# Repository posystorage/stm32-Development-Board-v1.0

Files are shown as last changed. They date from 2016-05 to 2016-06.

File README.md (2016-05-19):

# stm32-Development-Board-v1.0
话说事情起因是一元钱的pos机造成的，记得当初撸的第一个pos机是米刷的，然后就拆了gd32的单片机下来玩，焊在转接板上使用，100脚的转接板，插线很是的困难，经常插错线，还拿着程序调半天没结果。
后来又撸了几个即付宝，里面是stm32的单片机，不想忍受原装板子上基本上所有引脚都没引出，用不了，功能强大的stm32就是个残废，还不如个51，拆下来上转接板又难插线，心塞。
之前想加个小组织，说只会点51被人家鄙视说一点8位单片机搞不了什么大东西，所以想学stm32，看看芯片价格，tm一片（stm32）价格更比3片（51）强，在看看最小系统，tm价格又翻了三倍，开发板更贵了，穷学生伤不起。
正好这个寒假又自学了ad，画了一两个板子，自我感觉还好（其实现在看看一塌糊涂）。
于是在有天出去散步时就萌生了自己做块stm32开发板的想法，计算下感觉蛮合适的，单片机一块钱，板子打样5-6块，其他零件不超20，和起来还比一块最小系统便宜，越想越激动，散步都忙不急看风景了，回来就赶紧研究。
 
最终选择了以正点原子的板子为基础进行改造，这样有个好处，人家电路经过研究肯定没问题，比自己到处找简单，如果引脚差不多一样，程序也可以直接拿过来用，基本不用改，原子的例程，论坛的用这板子的大神的东西，都可以借鉴，同时也加了些玩51的时带不起来的遗憾的东西进去，比如iis、sdio式的sd卡接口、板载stlink（自己没有stlink，买还要钱，不如板载个吧，这样用起了更方便)、也加了平时很难焊接的esp8266焊盘。
这样一加这么多功能发觉，我去，io不够了，想来想去，特别烦躁的过过了两天，想了杜邦线连接式开发板（如有些51开发板就这样），想了各种引脚复用，最后一想到时候实际玩的时候要是刚好接在复用引脚上的东西就不能一起hi了，比如spi和iis只能选一个，用屏幕时不能用sdio等等，那是不是挺麻烦的。
最后做出一个重大的艰难的决定，吧屏幕接口扔了，这样不就省了20多个io，想怎么hi怎么hi，hi完还有剩余io，爽。其实还有另一层打算，之前只玩过12864和1602，对彩屏根本不了解，接口也不熟悉，看了好多款屏幕，各种接口都有，很不统一，如果直接照抄原子哥的屏幕接口，到时候搞不好买不到一样的，还只能去它店里剁手一块他定制的屏幕，那不就比两个自制开发板还贵了么？穷学生玩不起，算了，到时候大不了搞点黑白屏或者全部杜邦线连上，low就low点，自用管他的。

于是就这样，一块板子就做完了（真尼玛说的容易，学ad和stm32入门花了一个月，设计板子用了2周，工厂花了一周，焊接调试查错差不多花了一周，而且这些时间基本上除了正事外整天投入的，连干正事的时候都还经常想着下一步的计划），所以说不容易啊.

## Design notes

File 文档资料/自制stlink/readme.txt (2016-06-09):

1、建议焊接完成刷入固件后更新到最新版本固件
2、在开发板上刷入固件时，不要耍小聪明，一定要注意供电，建议不要用板载的3.3v稳压芯片供电，用下载器供电，必须必须必须接全3.3v、rx、tx（swd、sck）和gnd，不然会像我一样浪费一下午给stlink烧固件。供电问题表现为：串口下载检测不到芯片，stlink能检测到且下载，但校验不通过，检查发现，大半程序没烧入，呵呵，总体建议串口下载
3、板载stlink和主芯片有两个短接焊盘相连，如果只想下主控就连起来，不想就别连，我倒是没连，用杜邦线连，我要下载的板子多，只有这个stlink。

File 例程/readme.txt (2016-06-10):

部分内容与原子的不兼容，自行验证验证过的没问题

暂未测试/未成功内容：

iic，无24l01
iis，代码不会写，暂不测
sdio，原因不明，反正不成功，焊盘也有点问题
can，无芯片
ch340自动下载，买零件那天优信缺货，暂无
ps2，座子插不进去，也没相关设备

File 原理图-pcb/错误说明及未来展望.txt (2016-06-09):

2016/03/08版v1.0

------

问题；严重级别

1、usb差分走线问题；未知，主机和stlink测试无问题
2、pa2和pa3位置错误且丝印错误；中
3、串口rx tx与常用转串口下载器相反，需要交叉接线，麻烦；低
4、usb焊盘太短，芯片焊盘应加长；低
5、FLASH焊盘太短；低
6、板载stlink晶振周围太窄；低
7、ps2接口插不进去；低
8、tf卡（sdio接口）焊盘错误；中高

-----
第二版期望加入的功能：

1、蓝牙模块焊盘
2、usb静电保护芯片

第二版计划删除：
can
ps2
iis接口的adc芯片cs4344
esp8266
板载stlink

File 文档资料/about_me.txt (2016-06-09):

这是一块功能强大的stm32单片机开发板，由一个第一次画pcb的小屁孩逗逼制作。
起因是一元钱的pos机造成的，记得当初撸的第一个pos机是米刷的，然后就拆了gd32的单片机下来玩，焊在转接板上使用，100脚的转接板，插线很是的困难，经常插错线，还拿着程序调半天没结果。后来又撸了几个即付宝，里面是stm32的单片机，不想忍受原装板子上引脚基本用不了，功能强大的stm32就是个残废，拆下来上转接板又难插线，心塞。之前想加个小组织，说只会点51被人家鄙视说一点8位单片机搞不了什么大东西，所以想学stm32，看看芯片价格，tm一片（stm32）价格更比3片（51）强，在看看最小系统，tm价格又翻了三倍，开发板更贵了，穷学生伤不起。正好这个寒假又自学了ad，画了一两个板子，自我感觉还好（其实现在看看一塌糊涂）。于是在有天出去散步时就萌生了自己做块stm32开发板的想法，计算下感觉蛮合适的，单片机一块钱，板子打样5-6块，其他零件不超20，和起来还比一块最小系统便宜，越想越激动，散步都忙不急看风景了，回来就赶紧研究，最终选择了以正点原子的板子为基础进行改造，这样有个好处，人家电路经过研究肯定没问题，比自己到处找简单，如果引脚差不多一样，程序也可以直接拿过来用，基本不用改，原子的例程，论坛的用这板子的大神的东西，都可以借鉴，同时也加了些玩51的时带不起来的遗憾的东西进去，比如iis、sdio式的sd卡接口、板载stlink（自己没有stlink，买还要钱，不如板载个吧，这样用起了更方便)、也加了平时很难焊接的esp8266焊盘。这样一加发觉我去，io不够了，想来想去，特别烦躁的过过了两天，想了杜邦线连接式开发板（如有些51开发板就这样），想了各种引脚复用，最后一想到时候实际玩的时候要是刚好接在复用引脚上的东西就不能一起hi了，比如spi和iis只能选一个，用屏幕时不能用sdio等等，那是不是挺麻烦的。最后做出一个重大的艰难的决定，吧屏幕接口扔了，这样不就省了20多个io，想怎么hi怎么hi，hi、玩还有剩余io，爽。其实还有另一层打算，之前只玩过12864和1602，对彩屏根本不了解，接口也不熟悉，看了好多款屏幕，各种接口都有，很不统一，如果直接照抄原子哥的屏幕接口，到时候搞不好买不到一样的，还只能去它店里剁手一块他定制的屏幕，那不就比两个自制开发板还贵了么？穷学生玩不起，算了，到时候大不了搞点黑白屏或者全部杜邦线连上，low就low点，自用管他的。于是就这样，一块板子就做完了（真尼玛说的容易，学ad和stm32入门花了一个月，设计板子用了2周，工厂花了一周，焊接调试查错差不多花了一周，而且这些时间基本上除了正事外整天投入的，连干正事的时候都还经常想着下一步的计划），所以说不容易啊，就此先感谢大家的支持，你们的支持是我第二版的动力

关于第二版：
短期内暂时不想做，最近事多，干这个至少要报废一个月
如果坛友们的呼声特别大，才考虑
毕竟第一版问题不算太多，可以接受，不是急需第二版
还有其他项目

https://stm32-posystorage.rhcloud.com

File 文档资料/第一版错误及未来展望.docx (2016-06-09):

2016/03/08版v1.0

问题；严重级别

1、 usb差分走线问题；未知，主机和stlink测试无问题

板载stlink小概率不正常，不能识别上usb，主usb暂无此问题

2、pa2和pa3位置错误且丝印错误；中

Pa2的位置实际是pa3

Pa3的位置实际是pa2

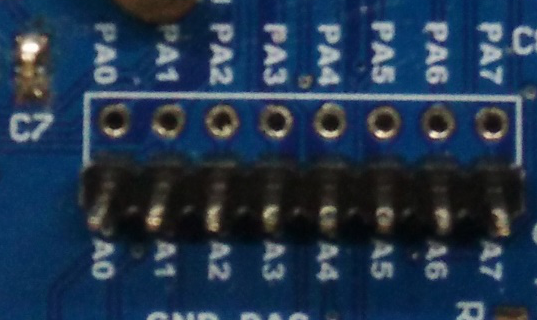
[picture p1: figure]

3、串口rx tx与常用转串口下载器相反，需要交叉接线，麻烦；低

4、usb焊盘太短，芯片焊盘应加长；低

5、FLASH焊盘太短；低

6、板载stlink晶振周围太窄；低

7、ps2接口插不进去；低

8、tf卡（sdio接口）焊盘错误；中高

只能这样焊才对，有点蛋疼

且程序验证暂未通过

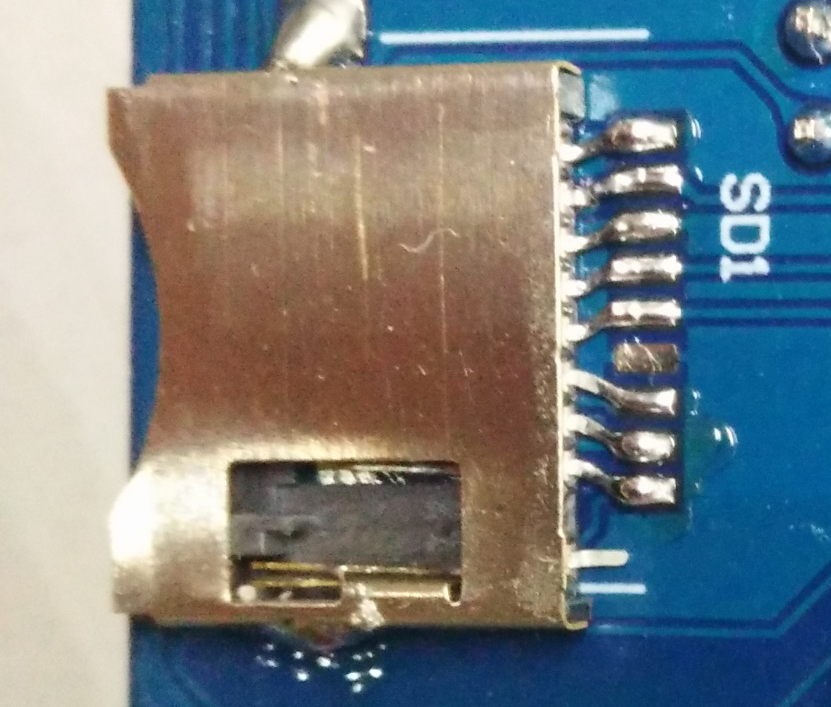
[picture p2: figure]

第二版期望加入的功能：

1、蓝牙模块焊盘

2、usb静电保护芯片

第二版计划删除：

can

ps2

iis接口的adc芯片cs4344

esp8266

板载stlink

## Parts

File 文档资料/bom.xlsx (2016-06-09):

简易bom表，凭记忆，可能不完全，注意复查，以电路图为准
名称 | 封装 | 数量 | 备注
stm32f103rct6 |  | 1
stm32f103c8t6 |  | 1
8m晶振 |  | 2
12m晶振 |  | 1
时钟晶振 | 圆柱 | 1
排针排座 |  | 若干
自恢复保险丝 | 1812 | 1 | 500ma
usb | micro | 3
1n4148 | 1206 | 1
耳机座 |  | 1
ps/2插座 |  | 1
按键 |  | 4
led | 0805以下 | 5
ams1117-3.3 |  | 1
led5050 | 5050 | 1 | 三色
8550 | SOT-23B_N | 1
8050 | SOT-24B_N | 1
电阻 | 0805以下 | 若干 | 1m,47k,10k,4k7,1k5,1k,r100,r22
电容 | 0805以下 | 若干 | 106,104(多),22p
电解电容 |  | 6 | 3.3uf，其他
tf卡座 |  | 1 | 优信有卖同封装
sd卡座 |  | 1 | 优信有卖同封装
tja1050 | sop8 | 1
短路帽 |  | 4
ch340 |  | 1
cs4344 |  | 1
25q32 |  | 1 | flash
esp8266模块 | esp12f | 1

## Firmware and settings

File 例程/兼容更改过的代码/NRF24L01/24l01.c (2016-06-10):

#include "24l01.h"
#include "delay.h"
#include "spi.h"
//////////////////////////////////////////////////////////////////////////////////	 
//本程序只供学习使用，未经作者许可，不得用于其它任何用途
//ALIENTEK MiniSTM32开发板
//NRF24L01驱动代码	   
//正点原子@ALIENTEK
//技术论坛:www.openedv.com
//修改日期:2014/3/12
//版本：V1.0
//版权所有，盗版必究。
//Copyright(C) 广州市星翼电子科技有限公司 2009-2019
//All rights reserved									  
//////////////////////////////////////////////////////////////////////////////////
    
const u8 TX_ADDRESS[TX_ADR_WIDTH]={0x34,0x43,0x10,0x10,0x01}; //发送地址
const u8 RX_ADDRESS[RX_ADR_WIDTH]={0x34,0x43,0x10,0x10,0x01}; //发送地址


//初始化24L01的IO口

void NRF24L01_Init(void)
{  
	GPIO_InitTypeDef GPIO_InitStructure;
	SPI_InitTypeDef  SPI_InitStructure; 
	
 	RCC_APB2PeriphClockCmd(	RCC_APB2Periph_GPIOA|RCC_APB2Periph_GPIOB|RCC_APB2Periph_GPIOC, ENABLE );	
	
	GPIO_InitStructure.GPIO_Pin = GPIO_Pin_2|GPIO_Pin_3|GPIO_Pin_4;
	GPIO_InitStructure.GPIO_Mode = GPIO_Mode_Out_PP ;   //推挽输出
	GPIO_InitStructure.GPIO_Speed = GPIO_Speed_50MHz;
	GPIO_Init(GPIOA, &GPIO_InitStructure);
	
	GPIO_InitStructure.GPIO_Pin = GPIO_Pin_4;
	GPIO_InitStructure.GPIO_Mode = GPIO_Mode_Out_PP ;   //推挽输出
	GPIO_InitStructure.GPIO_Speed = GPIO_Speed_50MHz;
	GPIO_Init(GPIOC, &GPIO_InitStructure); 
	GPIO_SetBits(GPIOC,GPIO_Pin_4);
		
	GPIO_InitStructure.GPIO_Pin = GPIO_Pin_0;
	GPIO_InitStructure.GPIO_Mode = GPIO_Mode_Out_PP ;   //推挽输出
	GPIO_InitStructure.GPIO_Speed = GPIO_Speed_50MHz;
	GPIO_Init(GPIOB, &GPIO_InitStructure); 
	GPIO_SetBits(GPIOB,GPIO_Pin_0);
	
	GPIO_InitStructure.GPIO_Pin = GPIO_Pin_1;
	GPIO_InitStructure.GPIO_Mode = GPIO_Mode_IPU  ;   //上拉输入
	GPIO_InitStructure.GPIO_Speed = GPIO_Speed_50MHz;
	GPIO_Init(GPIOA, &GPIO_InitStructure);

	GPIO_SetBits(GPIOA,GPIO_Pin_1|GPIO_Pin_2|GPIO_Pin_3|GPIO_Pin_4);
	SPI1_Init();    		//初始化SPI
		
	SPI_Cmd(SPI1, DISABLE); // 
	
	SPI_InitStructure.SPI_Direction = SPI_Direction_2Lines_FullDuplex;  //设置SPI单向或者双向的数据模式:SPI设置为双线双向全双工
	SPI_InitStructure.SPI_Mode = SPI_Mode_Master;		//设置SPI工作模式:设置为主SPI
	SPI_InitStructure.SPI_DataSize = SPI_DataSize_8b;		//设置SPI的数据大小:SPI发送接收8位帧结构
	SPI_InitStructure.SPI_CPOL = SPI_CPOL_Low;		//选择了串行时钟的稳态:时钟悬空低电平
	SPI_InitStructure.SPI_CPHA = SPI_CPHA_1Edge;	//数据捕获于第一个时钟沿
	SPI_InitStructure.SPI_NSS = SPI_NSS_Soft;		//NSS信号由硬件（NSS管脚）还是软件（使用SSI位）管理:内部NSS信号有SSI位控制
	SPI_InitStructure.SPI_BaudRatePrescaler = SPI_BaudRatePrescaler_256;		//定义波特率预分频的值:波特率预分频值为256
	SPI_InitStructure.SPI_FirstBit = SPI_FirstBit_MSB;	//指定数据传输从MSB位还是LSB位开始:数据传输从MSB位开始
	SPI_InitStructure.SPI_CRCPolynomial = 7;	//CRC值计算的多项式
	SPI_Init(SPI1, &SPI_InitStructure);  //根据SPI_InitStruct中指定的参数初始化外设SPIx寄存器

	
	NRF24L01_CE=0; 	//使能24L01
	NRF24L01_CSN=1;	//SPI片选取消	 	
}
//检测24L01是否存在
//返回值:0，成功;1，失败	
u8 NRF24L01_Check(void)
{
	u8 buf[5]={0XA5,0XA5,0XA5,0XA5,0XA5};
	u8 i;
	SPI1_SetSpeed(SPI_BaudRatePrescaler_8); //spi速度为9Mhz（24L01的最大SPI时钟为10Mhz）   	 
	NRF24L01_Write_Buf(NRF_WRITE_REG+TX_ADDR,buf,5);//写入5个字节的地址.	
	NRF24L01_Read_Buf(TX_ADDR,buf,5); //读出写入的地址  
	for(i=0;i<5;i++)if(buf[i]!=0XA5)break;	 							   
	if(i!=5)return 1;//检测24L01错误	
	return 0;		 //检测到24L01
}	 	 
//SPI写寄存器
//reg:指定寄存器地址
//value:写入的值
u8 NRF24L01_Write_Reg(u8 reg,u8 value)
{
	u8 status;	
   	NRF24L01_CSN=0;                 //使能SPI传输
  	status =SPI1_ReadWriteByte(reg);//发送寄存器号 
  	SPI1_ReadWriteByte(value);      //写入寄存器的值
  	NRF24L01_CSN=1;                 //禁止SPI传输	   
  	return(status);       			//返回状态值
}
//读取SPI寄存器值
//reg:要读的寄存器
u8 NRF24L01_Read_Reg(u8 reg)
{
	u8 reg_val;	    
 	NRF24L01_CSN = 0;          //使能SPI传输		
  	SPI1_ReadWriteByte(reg);   //发送寄存器号
  	reg_val=SPI1_ReadWriteByte(0XFF);//读取寄存器内容
  	NRF24L01_CSN = 1;          //禁止SPI传输		    
  	return(reg_val);           //返回状态值
}	
//在指定位置读出指定长度的数据
//reg:寄存器(位置)
//*pBuf:数据指针
//len:数据长度
//返回值,此次读到的状态寄存器值 
u8 NRF24L01_Read_Buf(u8 reg,u8 *pBuf,u8 len)
{
	u8 status,u8_ctr;	       
  	NRF24L01_CSN = 0;           //使能SPI传输
  	status=SPI1_ReadWriteByte(reg);//发送寄存器值(位置),并读取状态值   	   
 	for(u8_ctr=0;u8_ctr<len;u8_ctr++)pBuf[u8_ctr]=SPI1_ReadWriteByte(0XFF);//读出数据
  	NRF24L01_CSN=1;       //关闭SPI传输
  	return status;        //返回读到的状态值
}
//在指定位置写指定长度的数据
//reg:寄存器(位置)
//*pBuf:数据指针
//len:数据长度
//返回值,此次读到的状态寄存器值
u8 NRF24L01_Write_Buf(u8 reg, u8 *pBuf, u8 len)
{
	u8 status,u8_ctr;	    
 	NRF24L01_CSN = 0;          //使能SPI传输
  	status = SPI1_ReadWriteByte(reg);//发送寄存器值(位置),并读取状态值
  	for(u8_ctr=0; u8_ctr<len; u8_ctr++)SPI1_ReadWriteByte(*pBuf++); //写入数据	 
  	NRF24L01_CSN = 1;       //关闭SPI传输
  	return status;          //返回读到的状态值
}				   
//启动NRF24L01发送一次数据
//txbuf:待发送数据首地址
//返回值:发送完成状况
u8 NRF24L01_TxPacket(u8 *txbuf)
{
	u8 sta;
 	SPI1_SetSpeed(SPI_BaudRatePrescaler_8);//spi速度为9Mhz（24L01的最大SPI时钟为10Mhz）   
	NRF24L01_CE=0;
  	NRF24L01_Write_Buf(WR_TX_PLOAD,txbuf,TX_PLOAD_WIDTH);//写数据到TX BUF  32个字节
 	NRF24L01_CE=1;//启动发送	   
	while(NRF24L01_IRQ!=0);//等待发送完成
	sta=NRF24L01_Read_Reg(STATUS);  //读取状态寄存器的值	   
	NRF24L01_Write_Reg(NRF_WRITE_REG+STATUS,sta); //清除TX_DS或MAX_RT中断标志
	if(sta&MAX_TX)//达到最大重发次数
	{
		NRF24L01_Write_Reg(FLUSH_TX,0xff);//清除TX FIFO寄存器 
		return MAX_TX; 
	}
	if(sta&TX_OK)//发送完成
	{
		return TX_OK;
	}
	return 0xff;//其他原因发送失败
}
//启动NRF24L01发送一次数据
//txbuf:待发送数据首地址
//返回值:0，接收完成；其他，错误代码
u8 NRF24L01_RxPacket(u8 *rxbuf)
{
	u8 sta;		    							   
	SPI1_SetSpeed(SPI_BaudRatePrescaler_8); //spi速度为9Mhz（24L01的最大SPI时钟为10Mhz）   
	sta=NRF24L01_Read_Reg(STATUS);  //读取状态寄存器的值    	 
	NRF24L01_Write_Reg(NRF_WRITE_REG+STATUS,sta); //清除TX_DS或MAX_RT中断标志
	if(sta&RX_OK)//接收到数据
	{
		NRF24L01_Read_Buf(RD_RX_PLOAD,rxbuf,RX_PLOAD_WIDTH);//读取数据
		NRF24L01_Write_Reg(FLUSH_RX,0xff);//清除RX FIFO寄存器 
		return 0; 
	}	   
	return 1;//没收到任何数据
}					    
//该函数初始化NRF24L01到RX模式
//设置RX地址,写RX数据宽度,选择RF频道,波特率和LNA HCURR
//当CE变高后,即进入RX模式,并可以接收数据了		   
void NRF24L01_RX_Mode(void)
{
	NRF24L01_CE=0;	  
  	NRF24L01_Write_Buf(NRF_WRITE_REG+RX_ADDR_P0,(u8*)RX_ADDRESS,RX_ADR_WIDTH);//写RX节点地址
	  
  	NRF24L01_Write_Reg(NRF_WRITE_REG+EN_AA,0x01);    	//使能通道0的自动应答    
  	NRF24L01_Write_Reg(NRF_WRITE_REG+EN_RXADDR,0x01);	//使能通道0的接收地址  	 
  	NRF24L01_Write_Reg(NRF_WRITE_REG+RF_CH,40);	    	//设置RF通信频率		  
  	NRF24L01_Write_Reg(NRF_WRITE_REG+RX_PW_P0,RX_PLOAD_WIDTH);//选择通道0的有效数据宽度 	    
  	NRF24L01_Write_Reg(NRF_WRITE_REG+RF_SETUP,0x0f);	//设置TX发射参数,0db增益,2Mbps,低噪声增益开启   
  	NRF24L01_Write_Reg(NRF_WRITE_REG+CONFIG, 0x0f);		//配置基本工作模式的参数;PWR_UP,EN_CRC,16BIT_CRC,接收模式 
  	NRF24L01_CE = 1; //CE为高,进入接收模式 
}
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

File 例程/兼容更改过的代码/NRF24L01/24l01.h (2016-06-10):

#ifndef __24L01_H
#define __24L01_H	 		  
#include "sys.h"   
//////////////////////////////////////////////////////////////////////////////////	 
//本程序只供学习使用，未经作者许可，不得用于其它任何用途
//ALIENTEK MiniSTM32开发板
//NRF24L01驱动代码	   
//正点原子@ALIENTEK
//技术论坛:www.openedv.com
//修改日期:2014/3/12
//版本：V1.0
//版权所有，盗版必究。
//Copyright(C) 广州市星翼电子科技有限公司 2009-2019
//All rights reserved									  
//////////////////////////////////////////////////////////////////////////////////

//////////////////////////////////////////////////////////////////////////////////////////////////////////
//NRF24L01寄存器操作命令
#define NRF_READ_REG    0x00  //读配置寄存器,低5位为寄存器地址
#define NRF_WRITE_REG   0x20  //写配置寄存器,低5位为寄存器地址
#define RD_RX_PLOAD     0x61  //读RX有效数据,1~32字节
#define WR_TX_PLOAD     0xA0  //写TX有效数据,1~32字节
#define FLUSH_TX        0xE1  //清除TX FIFO寄存器.发射模式下用
#define FLUSH_RX        0xE2  //清除RX FIFO寄存器.接收模式下用
#define REUSE_TX_PL     0xE3  //重新使用上一包数据,CE为高,数据包被不断发送.
#define NOP             0xFF  //空操作,可以用来读状态寄存器	 
//SPI(NRF24L01)寄存器地址
#define CONFIG          0x00  //配置寄存器地址;bit0:1接收模式,0发射模式;bit1:电选择;bit2:CRC模式;bit3:CRC使能;
                              //bit4:中断MAX_RT(达到最大重发次数中断)使能;bit5:中断TX_DS使能;bit6:中断RX_DR使能
#define EN_AA           0x01  //使能自动应答功能  bit0~5,对应通道0~5
#define EN_RXADDR       0x02  //接收地址允许,bit0~5,对应通道0~5
#define SETUP_AW        0x03  //设置地址宽度(所有数据通道):bit1,0:00,3字节;01,4字节;02,5字节;
#define SETUP_RETR      0x04  //建立自动重发;bit3:0,自动重发计数器;bit7:4,自动重发延时 250*x+86us
#define RF_CH           0x05  //RF通道,bit6:0,工作通道频率;
#define RF_SETUP        0x06  //RF寄存器;bit3:传输速率(0:1Mbps,1:2Mbps);bit2:1,发射功率;bit0:低噪声放大器增益
#define STATUS          0x07  //状态寄存器;bit0:TX FIFO满标志;bit3:1,接收数据通道号(最大:6);bit4,达到最多次重发
                              //bit5:数据发送完成中断;bit6:接收数据中断;
#define MAX_TX  		0x10  //达到最大发送次数中断
#define TX_OK   		0x20  //TX发送完成中断
#define RX_OK   		0x40  //接收到数据中断

#define OBSERVE_TX      0x08  //发送检测寄存器,bit7:4,数据包丢失计数器;bit3:0,重发计数器
#define CD              0x09  //载波检测寄存器,bit0,载波检测;
#define RX_ADDR_P0      0x0A  //数据通道0接收地址,最大长度5个字节,低字节在前
#define RX_ADDR_P1      0x0B  //数据通道1接收地址,最大长度5个字节,低字节在前
#define RX_ADDR_P2      0x0C  //数据通道2接收地址,最低字节可设置,高字节,必须同RX_ADDR_P1[39:8]相等;
#define RX_ADDR_P3      0x0D  //数据通道3接收地址,最低字节可设置,高字节,必须同RX_ADDR_P1[39:8]相等;
#define RX_ADDR_P4      0x0E  //数据通道4接收地址,最低字节可设置,高字节,必须同RX_ADDR_P1[39:8]相等;
#define RX_ADDR_P5      0x0F  //数据通道5接收地址,最低字节可设置,高字节,必须同RX_ADDR_P1[39:8]相等;
#define TX_ADDR         0x10  //发送地址(低字节在前),ShockBurstTM模式下,RX_ADDR_P0与此地址相等
#define RX_PW_P0        0x11  //接收数据通道0有效数据宽度(1~32字节),设置为0则非法
#define RX_PW_P1        0x12  //接收数据通道1有效数据宽度(1~32字节),设置为0则非法
#define RX_PW_P2        0x13  //接收数据通道2有效数据宽度(1~32字节),设置为0则非法
#define RX_PW_P3        0x14  //接收数据通道3有效数据宽度(1~32字节),设置为0则非法
#define RX_PW_P4        0x15  //接收数据通道4有效数据宽度(1~32字节),设置为0则非法
#define RX_PW_P5        0x16  //接收数据通道5有效数据宽度(1~32字节),设置为0则非法
#define NRF_FIFO_STATUS 0x17  //FIFO状态寄存器;bit0,RX FIFO寄存器空标志;bit1,RX FIFO满标志;bit2,3,保留
                              //bit4,TX FIFO空标志;bit5,TX FIFO满标志;bit6,1,循环发送上一数据包.0,不循环;
//////////////////////////////////////////////////////////////////////////////////////////////////////////
//24L01操作线
#define NRF24L01_CE   PBout(0) //24L01片选信号
#define NRF24L01_CSN  PCout(4) //SPI片选信号	   
#define NRF24L01_IRQ  PAin(1)  //IRQ主机数据输入
//24L01发送接收数据宽度定义
#define TX_ADR_WIDTH    5   	//5字节的地址宽度
#define RX_ADR_WIDTH    5   	//5字节的地址宽度
#define TX_PLOAD_WIDTH  32  	//32字节的用户数据宽度
#define RX_PLOAD_WIDTH  32  	//32字节的用户数据宽度
									   	   

void NRF24L01_Init(void);//初始化
void NRF24L01_RX_Mode(void);//配置为接收模式
void NRF24L01_TX_Mode(void);//配置为发送模式
u8 NRF24L01_Write_Buf(u8 reg, u8 *pBuf, u8 u8s);//写数据区
u8 NRF24L01_Read_Buf(u8 reg, u8 *pBuf, u8 u8s);//读数据区		  
u8 NRF24L01_Read_Reg(u8 reg);			//读寄存器
u8 NRF24L01_Write_Reg(u8 reg, u8 value);//写寄存器
u8 NRF24L01_Check(void);//检查24L01是否存在
u8 NRF24L01_TxPacket(u8 *txbuf);//发送一个包的数据
u8 NRF24L01_RxPacket(u8 *rxbuf);//接收一个包的数据
#endif

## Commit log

2016-06-09 上传资料
    [STLINK.SchDoc, STM32.PcbDoc, STM32.SchDoc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]
2016-06-10 上传例程
2016-06-10 新增mpu6050

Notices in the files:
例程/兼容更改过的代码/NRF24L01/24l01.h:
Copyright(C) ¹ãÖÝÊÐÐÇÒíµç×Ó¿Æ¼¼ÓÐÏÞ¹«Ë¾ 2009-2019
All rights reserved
